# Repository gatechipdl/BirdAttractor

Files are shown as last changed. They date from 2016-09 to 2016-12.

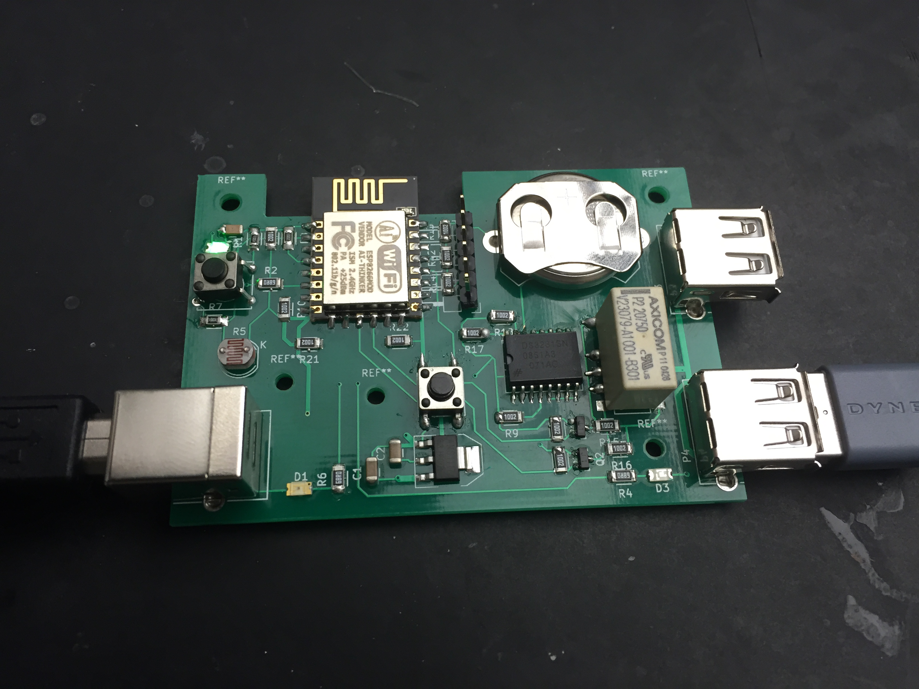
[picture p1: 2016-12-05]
Hardware/BirdAttractor_RevC/BirdAttractor_RevC-Assembled.jpg

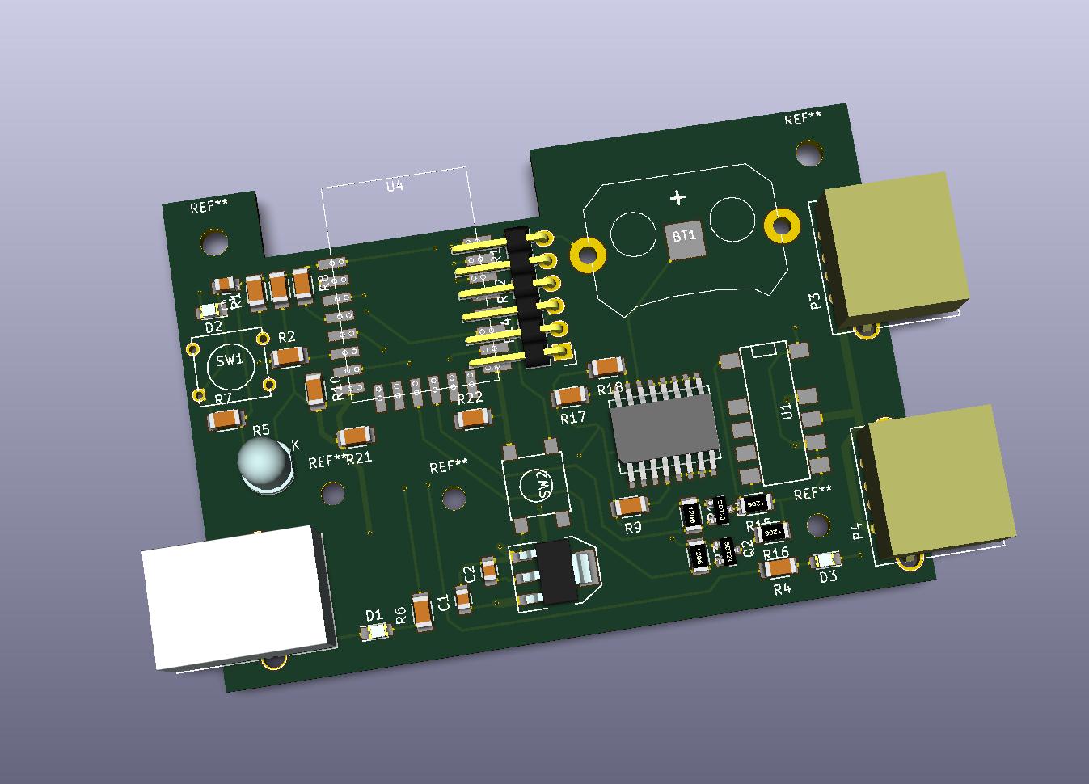
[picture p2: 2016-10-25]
Hardware/BirdAttractor_RevC/BirdAttractor_RevC-Render.jpg

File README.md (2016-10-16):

# BirdAttractor

## Requirements
- 5V Power input from in USB-B female form
- Two 5V Power output in USB-A female form
- Relay to control flow of at least 2A. Possibly more current support for better generalization. Most usb battery chargers are 2A, but some do 3A or 4A.
- Transistors to ensure relay coils trigger from MCU pins. ESP8266 can only drive 12mA on GPIO pins. Relays need >20mA.
 
- Ability to put microcontroller into deep sleep, waking up every 15 seconds to check for updates.
- Infinite alarms for super customization. Not interrupt based, only 15 second accuracy, due to deep sleep wakeup cycle.
- Ability to set the wakeup cycle from 1 second to 5 minutes. ESP8266 GPIO16 pulls CH-DP low during deep sleep. Anything that pulls 
 
- Microcontroller Interrupts for wakeup from deep sleep. ESP8266 can do this from the RTC on GPIO16 connected to reset.
- Two daily alarms for on and off settings. Interrupt based. The alarm interrupt on DS3231 only pulls down to 3mA, so it might need a transistor to boost the current capability to overcome the GPIO16 high signal when in deep_sleep.
 
- FTDI header pins with TX,RX,GND,5V for programming (could be removed if we can program using pogo pins and the firmware is completely debugged).
- Button to control Reset for programming. Button should ideally be hardware debounced, but could probably work without it. ESP8266 needs to pull Reset low, and then GPIO0 low to enter programming mode.
 
- Button to activate Wi-Fi for configuration.
- LED to notify users that the Wi-Fi is on. Should draw less than 12mA.
- LED to show that power is coming in. Should draw less than 12mA.
- LED to show that output power is switched on. Should draw less than 12mA.
 
- Voltage regulator to bring down 5V input to 3.3V for electronics. Should have decoupling capacitors to smooth the supply.
 
- Photoresistor to detect the amount of light for use as a trigger.
-- Ability to configure light based alarm. Five minute response time is sufficient.

- Temperature sensor. Can use the temperature sensor inside the TCXO RTC, which can be good enough.
 
- Real Time Clock with a temperature compensated crystal oscillator (TCXO).
-- Real Time Clock with sub 0C and very high temperature range with high accuracy.
-- Ability to set the timezone on the RTC.
-- Ability to push time from Wi-Fi connected device onto the MCU to update the RTC.

- Record the last X number of light and temperature readings along with when the power was turned on and off, and the timestamp.
-- Option to set the frequency of saving of readings.
-- Option to save X number of samples or to record until there is still memory available.
-- Option to cycle through the available memory or just stop recording when full.
-- Option to reset the samples by clearing the cache.
-- Option to visualize the data in a chart on the web interface.
-- Option to download the data to a Wi-Fi connected web client.
 
---------------
## LED
- Blue LED
- 150080BS75000
- Package:0805
- Forward Voltage: 3.2V
- Max Current: 20mA
- Current Limiting Resistor at 12mA: 16.6 ohms (E12=18 ohms or 22 ohms)
- $0.29@1, digi-key
- $0.23@100, digi-key

---------------
## RTC

### DS1305
- Arduino Library: https://github.com/cjbearman/ds1305-arduino
- Alarms:2
- has two alarms, each alarm must be reset by a read or write to the Alarm interrupt register. Must use an MCU to do this.
- The INT0 and INT1 interrupt output pins are pulled low, so when the alarm asserts, we have to have a pull-up resistor to bring the value up.
- It is likely the INT0 and INT1 pins may not be able to sink enough current to have a small pull up resistor. So with a larger value pull up resistor, the provided current on alarm assertion will be small as well. To magnify this current, a MOSFET may be needed.

### DS1307
- Arduino Library: DS1307RTC, Rtc by Makuna, RTCx 
- TXCO:No, not accurate enough

### DS3231
-Arduino Library: Rtc by Makuna, Sodaq_DS3231
#### DS3231SN
- has temperature compensated crystal oscillator (may need this for cold temps)
- TCXO:Yes
- Alamrs:2
- $9.97@1, digi-key
- $6.59@100, digi-key
- $2.50@10, aliexpress
#### DS3231M
- TCXO: unclear
- $6.46@1, digi-key
- $4.801@50, digi-key

### PCF2129
- TCXO:yes
- Arduino Library: FaBo 215 RTC PCF2129
#### PCF2129T
- Package:16-SOIC
- Temp:-30C to +80C
- $3.36@1, digi-key
- $2.47@100, digi-key
#### PCF2129AT
- Package:20-SOIC, similar as 16-SOIC but with 4 NC pins
- Temp:-15C to +60C
- $2.92@1, digi-key
- $2.15@100, digi-key

### PCF2127
- TXCO:Yes
- Arduino Library: I2C-Sensor-Lib iLib
- includes 512 bytes of general-purpose static RAM
#### PCF2127T
- Package:16-SOIC
- Temp:-30C to +80C
- $4.01@1, digi-key
- $2.95@100, digi-key
#### PCF2127AT
- Package:20-SOIC
- Temp:-15C to +60C
- $3.60@1, digi-key
- $2.65@100, digi-key
 
### PCA2129
- Arduino Library: None Found
- TXCO:Yes
#### PCA2129T
- Package:16-SOIC
- Temp:-30C to +80C
- $4.70@1, digi-key
- $3.46@100, digi-key

### MCP79400
- TXCO:No
- Arduino Library: RTCx (includes MCP7941x)
- accuracy potentially better than ds1307 and pcf8563, but not ds3231
- $0.82@1, digi-key
- $0.72@100, digi-key

---------------
## Relay
- latching, dual coil, bistable
- contact current: 2,3-10 Amps (2A seems an industry threshold)
- coil voltage: 3.3V,5V
- coil current: <100mA
- switching voltage: >5VDC

### V23079
- Current:2A
#### V23079-E1201-B301
- Signal Volage:3.75V-5V
- Signal Current:28mA
- Latching:Yes
- Bistable:Yes
- $3.69@1, digi-key
- $2.77@100, digi-key
#### V23079-A1001-B301
- $5.17@10, aliexpress
- Monstable:Yes
- Bistable:No
- standard coil, coil 001
- standard version, 2 form C contacts

### TX2SA
#### TX2SA-LT-5V-TH-Z
- Signal Volage:5V
- Signal Current:28.1mA
- Current:2A
- $5.83@1, digi-key
- $4.38@100, digi-key

### G6BK (5A, twice as expensive as 2A)
#### G6BK-1114P-US-DC5
- Signal Voltage:5V
- Signal Current:56mA
- Current:5A
- $7.61@1, digi-key
- $5.71@100, digi-key

### AQV25
- Type:solid state
### AQV251G
- Package:6-DIP
- Current:3.5A
- Voltage:0-30V
- $7.75@1, digi-key
- $5.85@100, digi-key
### AQV252G
- Package:6-SOIC
- Current:2.5A
- Voltage:0-60V
#### AQV252GAX
- Tape and Reel packaging on 123 pin side
- $5.39@1, digi-key
- $4.04@100, digi-key
#### AQV252GAZ
- Tape and Reel packaging on 456 pin side
#### AQV252GA
- Tube packing style

---------------
## Coin Cell Retainer/Holder
- Battery:CR2032
- Battery Diameter:20mm
### BU2032
#### BU2032-1-HD-G
- Type:through hole holder
- $0.83@1, digi-key
- $0.69@100, digi-key
#### BU2032SM-HD-G
- Type:surface mount holder
- $0.87@1, digi-key
- $0.76@100, digi-key
### BK
#### BK-913
- Type:through hole retainer
- Notes:easy replacement
- $0.35@1, digi-key
- $0.30@100, digi-key
#### BK-888
- Type:through hole retainer
- blocks inner side
- easy replacement
- $0.39@1, digi-key
- $0.33@100, digi-key

---------------
## LDO
- needed for running the esp8266 microprocessor
### AMS1117-3.3
- Package:SOT-223
- $1.58@50, aliexpress

---------------
## MCU
### ESP8266
- Wi-Fi:Yes
- Allows us to have a Wi-Fi interface for setting the time and other settings.
- VCC:3.3V
- Runs on 3.3V, so should have an LDO or similar to bring down the 5V supply.
- Should only be turned in two instances. First is to creating the Wi-Fi interface. Second is at an alarm, to turn off the alarm, and then shut itself down. If we use deep sleep, then we could check every 5 minutes (or less) to see if the alarm pin is pulled high.
- It might be possible to use the reset pin on the ESP8266 to wake it up with the alarm. This would be more power efficient and have better reaction time (within milliseconds) to the alarm assertion, but the solution is more complex and takes longer to develop. https://github.com/esp8266/Arduino/issues/1488
- pin mapping: http://www.esp8266.com/wiki/doku.php?id=esp8266_gpio_pin_allocations

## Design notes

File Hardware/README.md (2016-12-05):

RevA - first version
RevB - with correct parts, and partial design for in house milling; through hole parts flipped to bottom
RevC - layout with parts on top for fab house milling
 - problems
 -- smd button melts with 800 degree heat
 -- through-hole 6mm button legs don't fit well into holes
 -- missing a few 1206 sized resistors
 -- battery backwards due to kicad default battery pinout
 -- battery rotated backwards too on board; curved portion is where button slides in
 -- some LEDs on by default; check that is correct; should be able to disable
 -- relays are only monostable, not latching; only has one input; ok bc can be compensated for in code
 -- relays are throughole; should design for smd and tht too

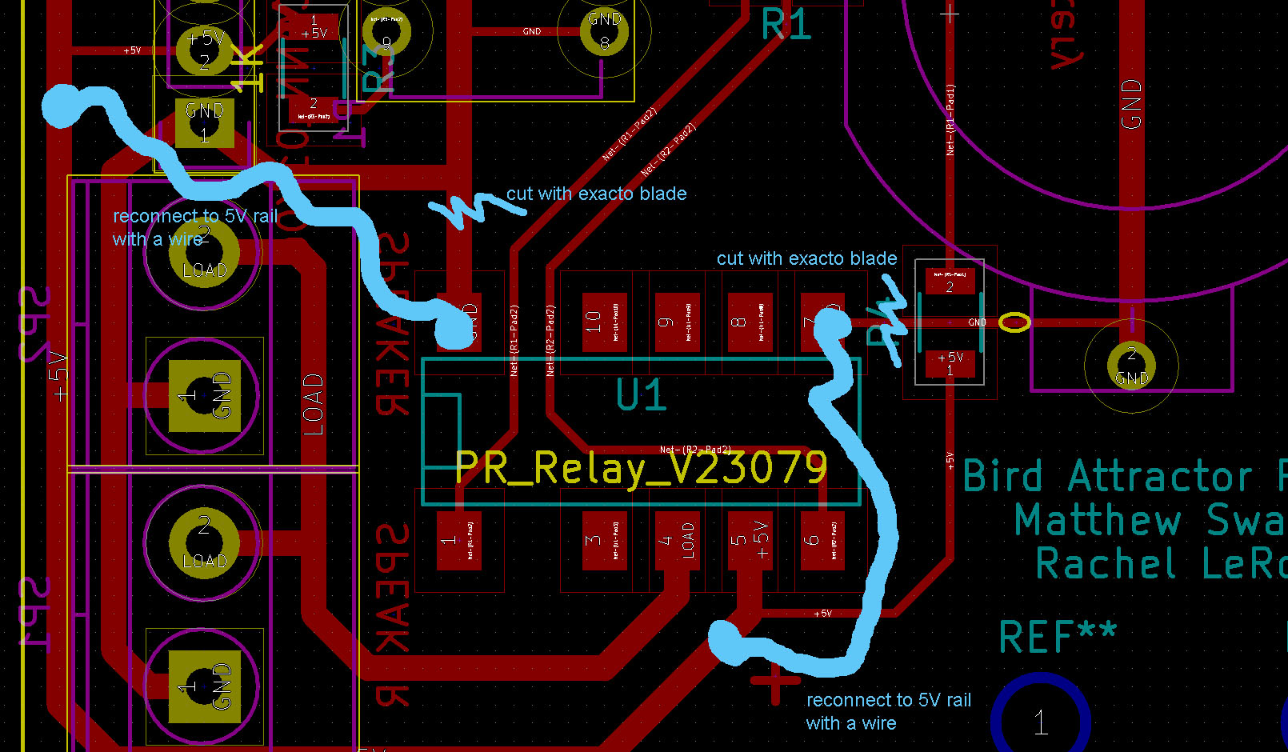
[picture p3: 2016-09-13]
Hardware/BirdAttractor_RevAFix.jpg

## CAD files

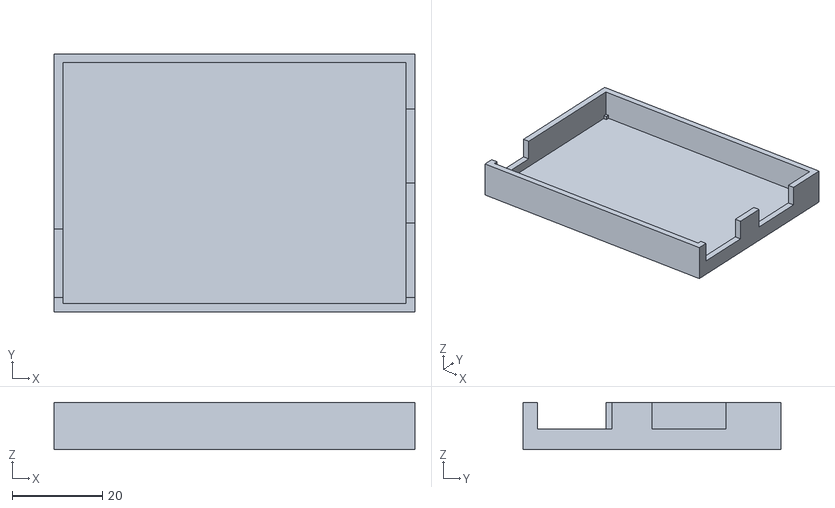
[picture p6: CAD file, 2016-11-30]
Models/3D.form.v1/bottom stl.stl
80.2 x 57.3 x 10.6

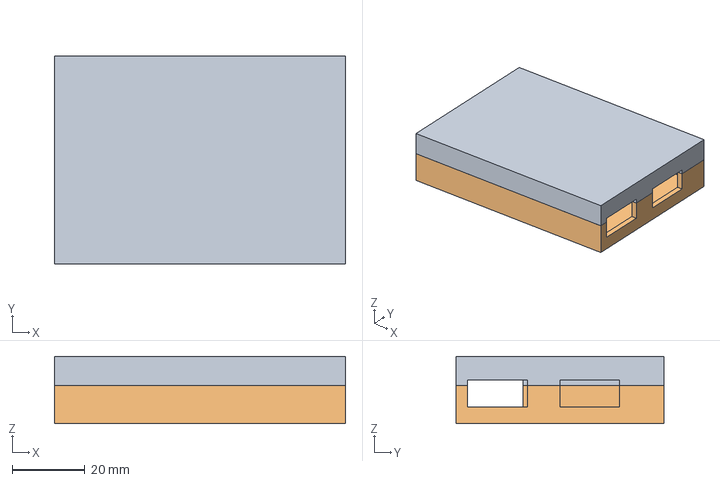
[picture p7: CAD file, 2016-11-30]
Models/3D.form.v1/box for hardware v9.step
80.2 x 57.3 x 18.5 mm
top
bottom

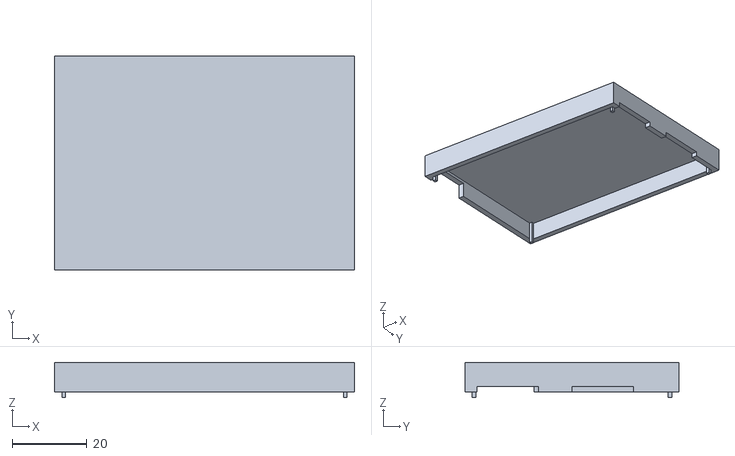
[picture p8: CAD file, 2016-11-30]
Models/3D.form.v1/top.stl
80.2 x 57.3 x 9.45

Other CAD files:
Models/3D.form.v1/box for hardware v9.f3d
Models/3D.form.v1/box for hardware v9.iges

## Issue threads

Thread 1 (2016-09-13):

design basic form for board components and case

strontium5, 2016-09-13:
arduino shield form
pin locations
power plug-ins
battery changing (every 8 years)

racheleleroy, 2016-10-31:
this isn't for the the 3D form, but for the UI. Couldn't figure out how to upload new file, kept saying I didn't have that authorization.

Very basic UI, still working on learning html, css, js but wanted to get some basic skeleton for mvp after doing the tutorials to exercise the new things in my head.
[bird attractor device rach's comp.zip](https://github.com/gatechipdl/BirdAttractor/files/561059/bird.attractor.device.rach.s.comp.zip)

strontium5, 2016-10-31:
this is for the 3D form

On Sun, Oct 30, 2016 at 11:35 PM, racheleleroy <notifications@github.com>
wrote:

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

strontium5, 2016-10-31:
You should be able to commit now.
Also, I added issues related to the UI. You can change them as you see fit.

racheleleroy, 2016-11-12:
3D files for the form to hold the board and components. Built in fusion360. The two stl files are each half of the box (top and bottom) separate so that they can easily be processed in the design shop. The other files are a variety of 3d files for good measure.

[3D form v1.zip](https://github.com/gatechipdl/BirdAttractor/files/587514/3D.form.v1.zip)

strontium5, 2016-11-30:
should be moved into the github code section under models ( I will create and do that now)

strontium5, 2016-11-30:
uploaded.
you can use the RevC pcb layout pdf file to get mounting hole and component positions for the next version of the case:
https://github.com/gatechipdl/BirdAttractor/blob/master/Hardware/BirdAttractor_RevC/BirdAttractor_RevC-Layout.pdf

strontium5, 2016-12-05:
@racheleleroy I added a photo of the assembled Rev C board. There are a few issues, but it should work. I haven't started on the basic firmware yet, but I did add the issues to the github issues list. I'll leave this board in our project box in the IPDL.

racheleleroy, 2016-12-06:
@strontium thanks for moving it to models and for the photo. Ill stop by and take a look at the board. I can have v2 by end of weekend. I'll slip it onto the design shop machines while I work this weekend

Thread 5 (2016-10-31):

design overall UI/UX for all pages hosted on device

strontium5, 2016-10-31:

racheleleroy, 2016-11-28:
[bird.att.take.two.zip](https://github.com/gatechipdl/BirdAttractor/files/615287/bird.att.take.two.zip)
Work on the bootstrap UI. No specific UI for picking date and time yet. There are some plugins we can use - going by the app lab tomorrow (monday) to get help understanding how to set them up across the html, css, and js

strontium5, 2016-11-30:
need to remove/replace references to external sites, such as for javascript libraries. This will not be connected to the internet.
This line is a problem:
<script src="//ajax.googleapis.com/ajax/libs/jquery/1.11.2/jquery.min.js"></script>
There is a local version of jquery in the js folder, which should be referenced instead.

It is looking alright so far. May need to distinguish between first time users, and those who just want to go and set the time.

While this device is being developed for the bird attractor, it is really much more generic than that. It is a device for setting 5v relay alarms over wifi. Should we make a distinction in the text (ie scientist vs user)?

strontium5, 2016-11-30:
Also, you can just put your code into the github. You won't need to create different version names for this code either, as github will maintain every version. I can put it in if you want. But eventually you should learn how to use git.

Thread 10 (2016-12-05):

swap out SW1 from 6mm to 12mm tht button

strontium5, 2016-12-05:

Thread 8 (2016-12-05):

fix coin cell battery orientations

strontium5, 2016-12-05:
rotated 180 degrees and the positive and ground are reversed

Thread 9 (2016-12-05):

redesign relay pinouts to support smd and tht and for mono and bi stable versions

strontium5, 2016-12-05:

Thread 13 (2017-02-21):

optionally replace relay with a power mosfet

strontium5, 2017-02-21:
power mosfet is cheaper and more powerful than relay for small voltages (eg 5V).
pnp power mosfet should probably use npn bjt before to increase the Vgs
npn bjt could be 2n3904 or 2n2222
pnp power mosfet could be FQP27P06 or Si3483

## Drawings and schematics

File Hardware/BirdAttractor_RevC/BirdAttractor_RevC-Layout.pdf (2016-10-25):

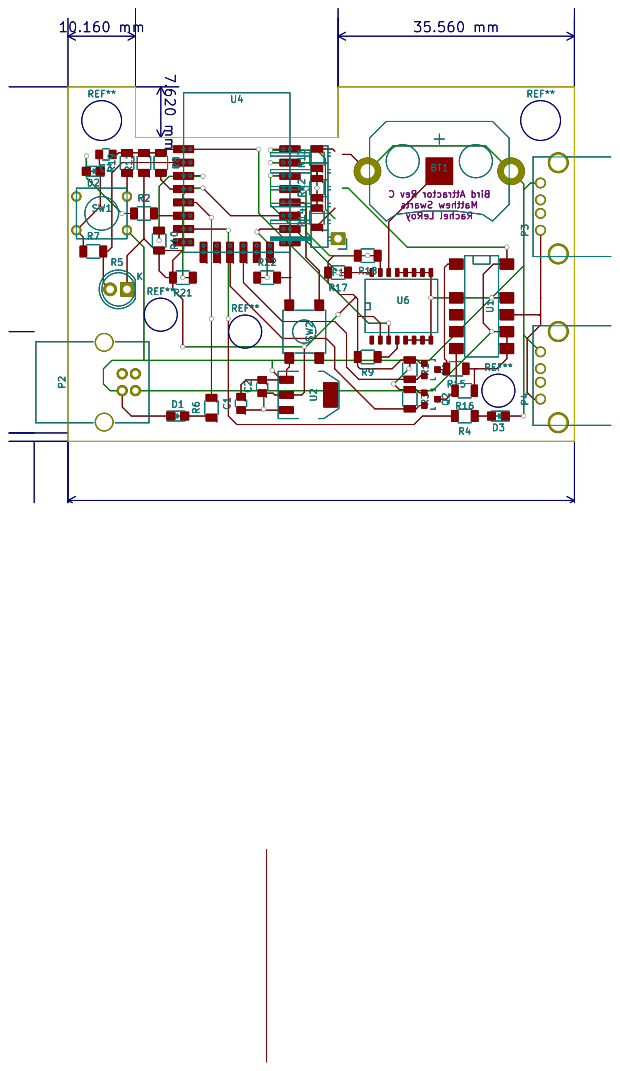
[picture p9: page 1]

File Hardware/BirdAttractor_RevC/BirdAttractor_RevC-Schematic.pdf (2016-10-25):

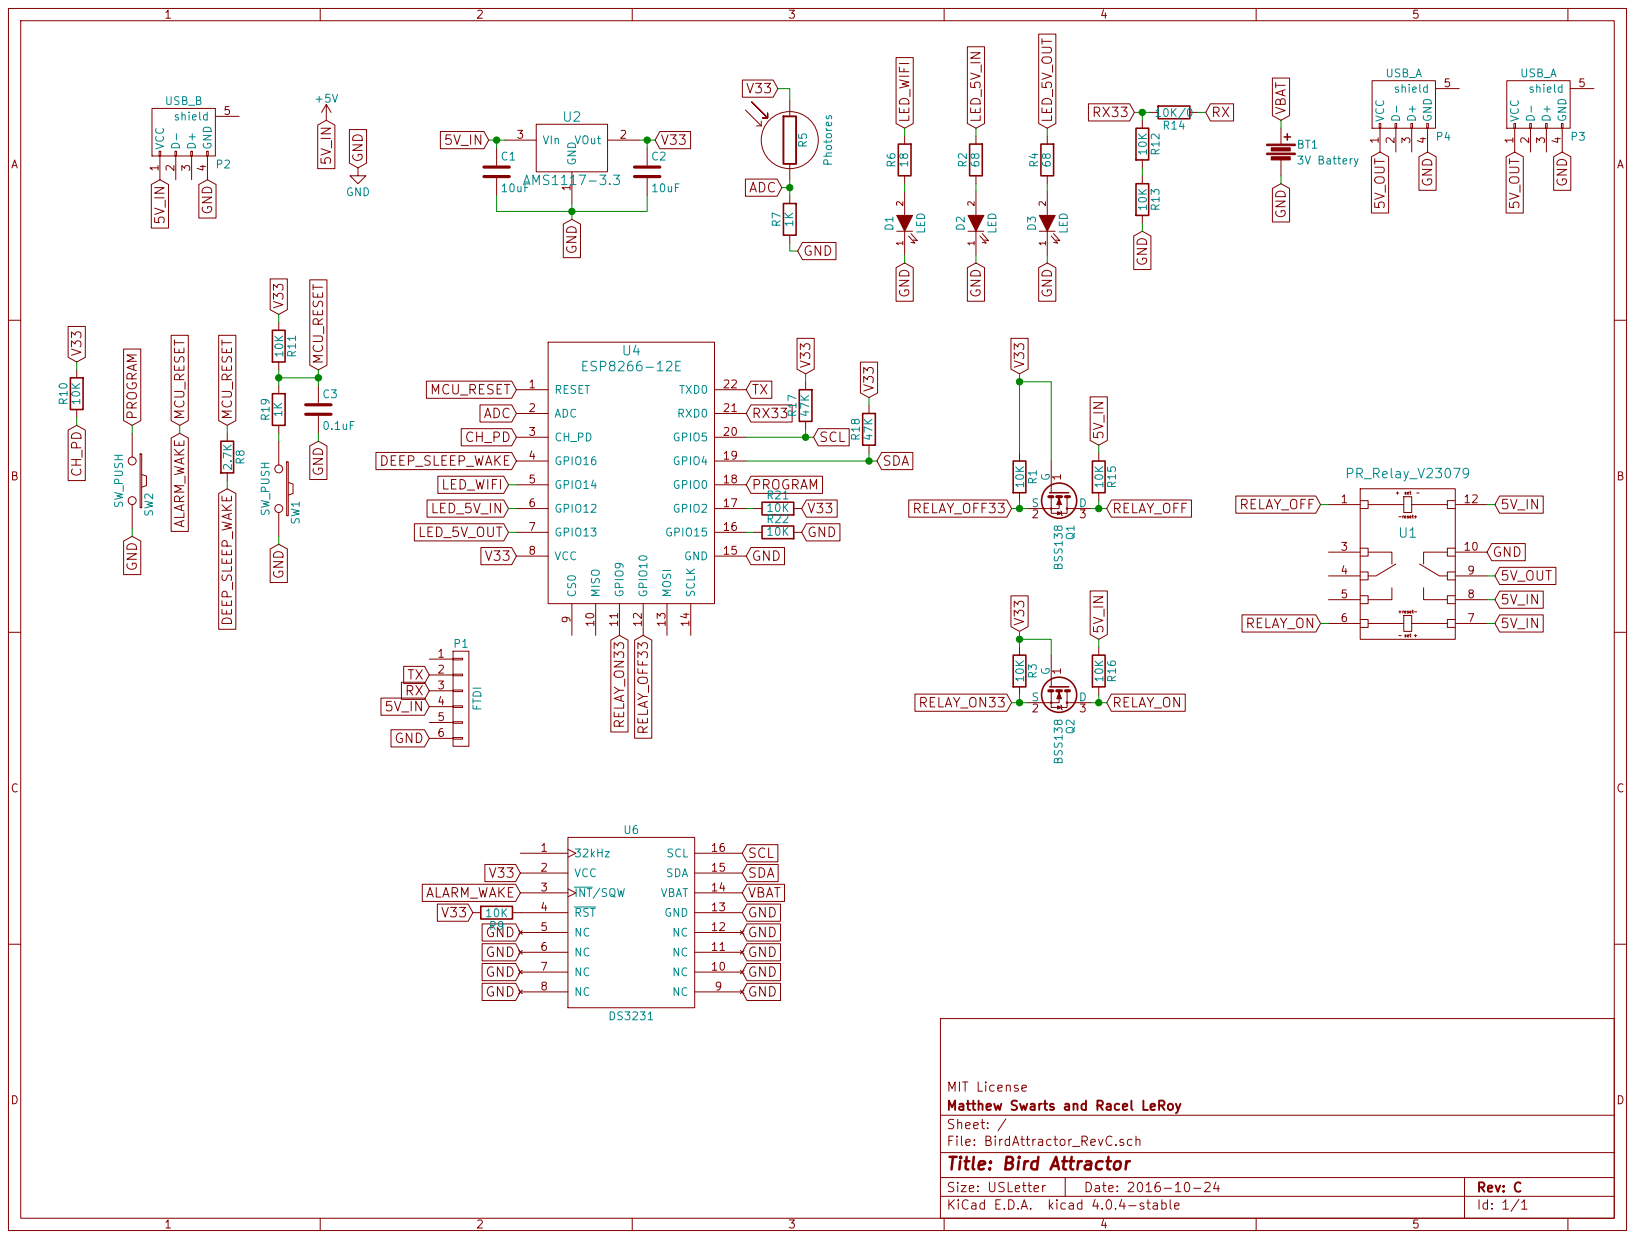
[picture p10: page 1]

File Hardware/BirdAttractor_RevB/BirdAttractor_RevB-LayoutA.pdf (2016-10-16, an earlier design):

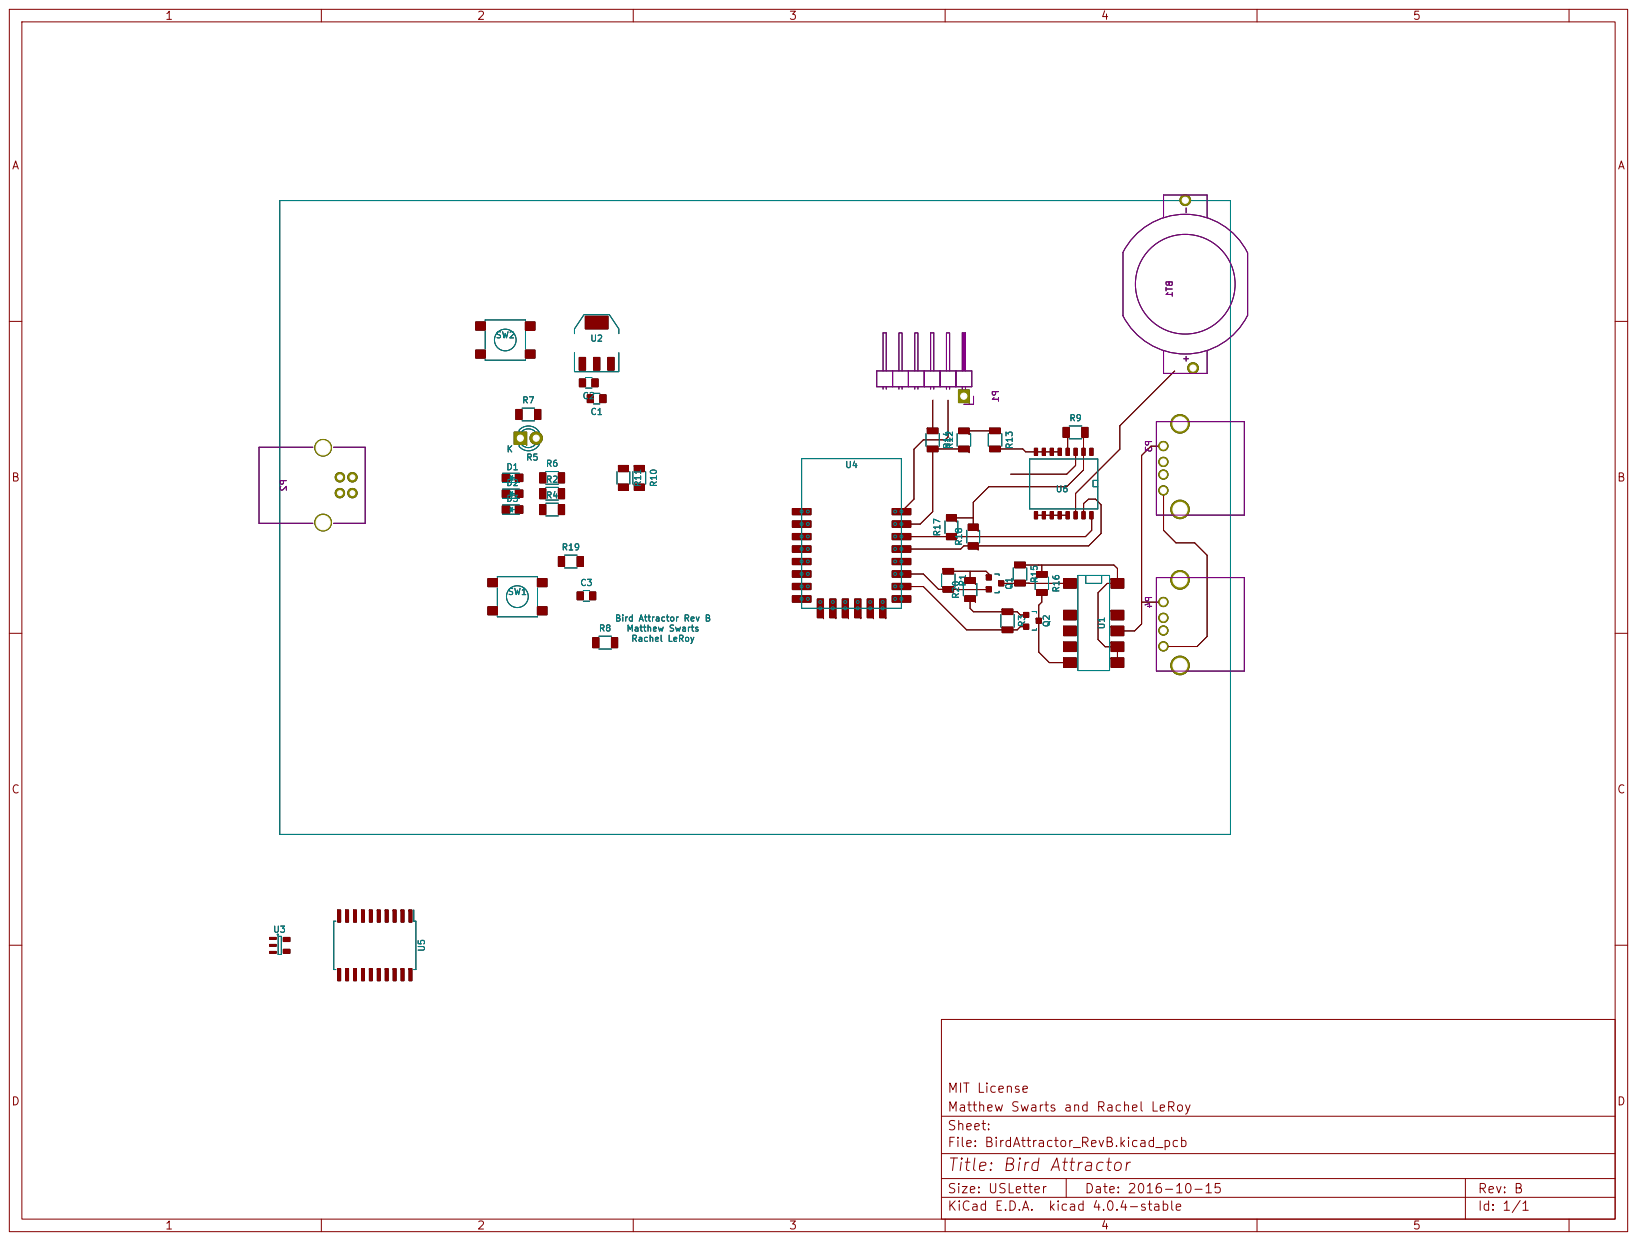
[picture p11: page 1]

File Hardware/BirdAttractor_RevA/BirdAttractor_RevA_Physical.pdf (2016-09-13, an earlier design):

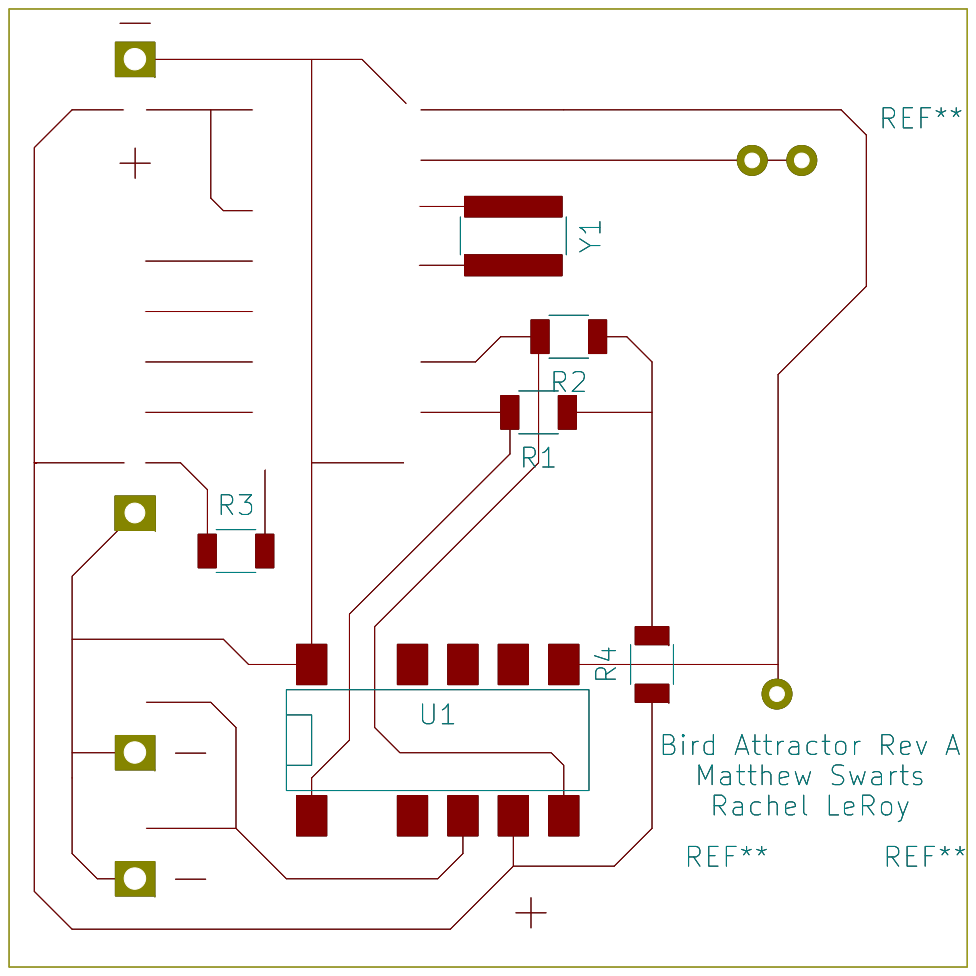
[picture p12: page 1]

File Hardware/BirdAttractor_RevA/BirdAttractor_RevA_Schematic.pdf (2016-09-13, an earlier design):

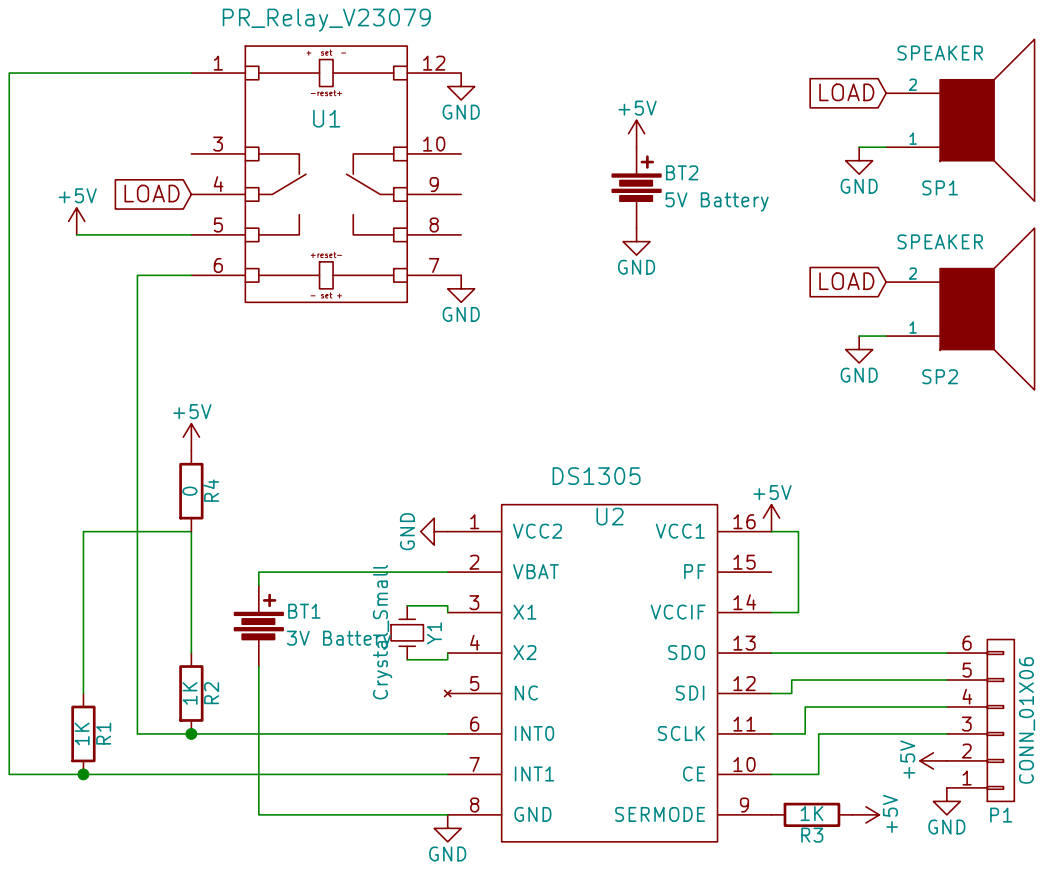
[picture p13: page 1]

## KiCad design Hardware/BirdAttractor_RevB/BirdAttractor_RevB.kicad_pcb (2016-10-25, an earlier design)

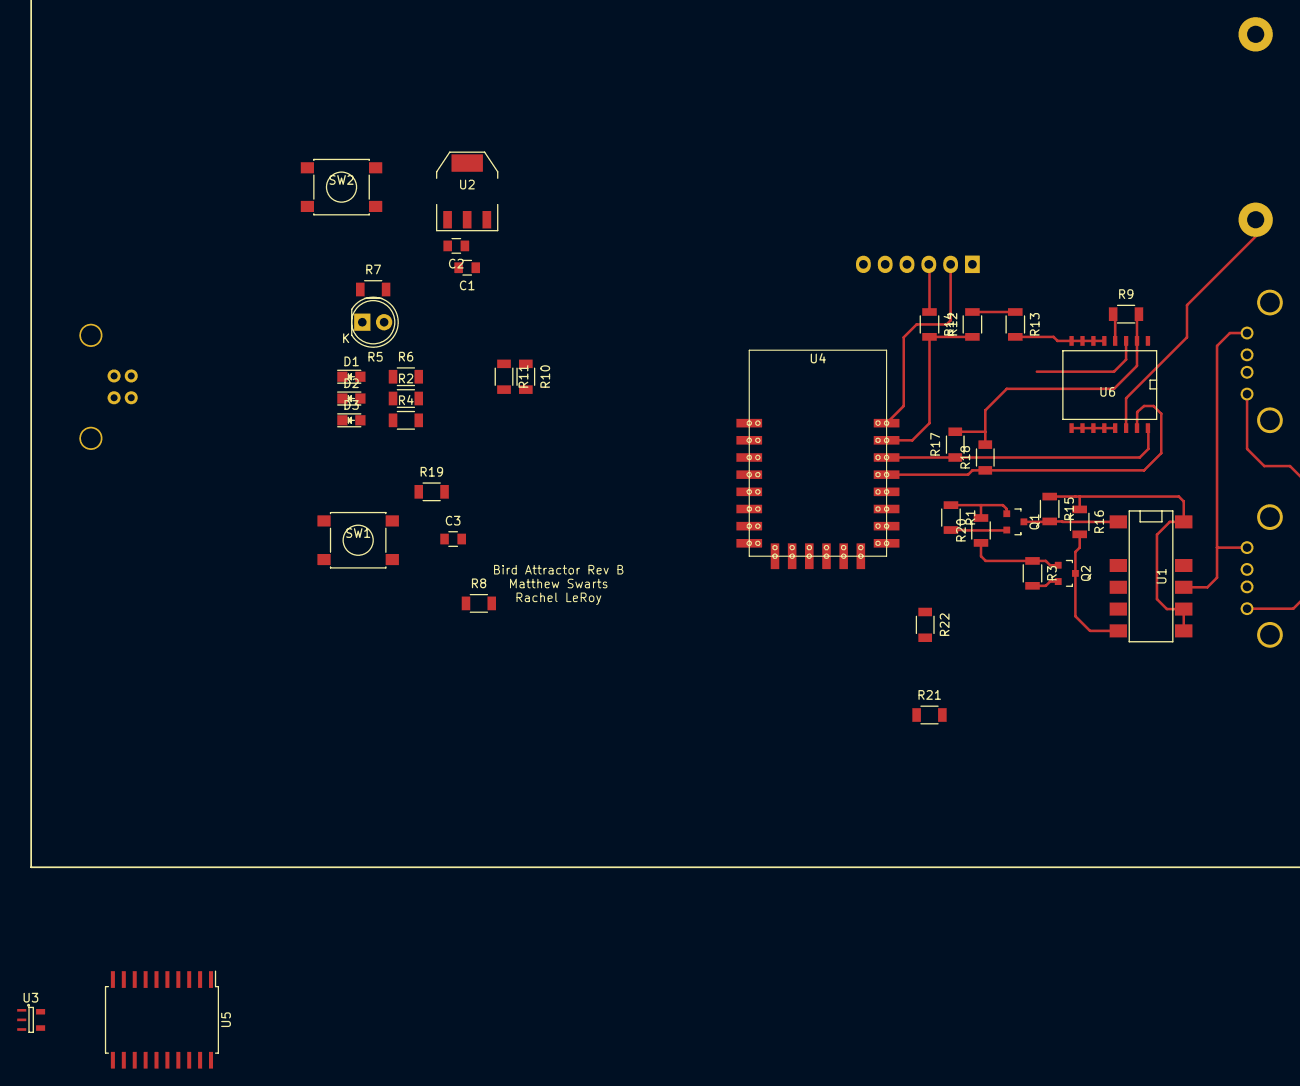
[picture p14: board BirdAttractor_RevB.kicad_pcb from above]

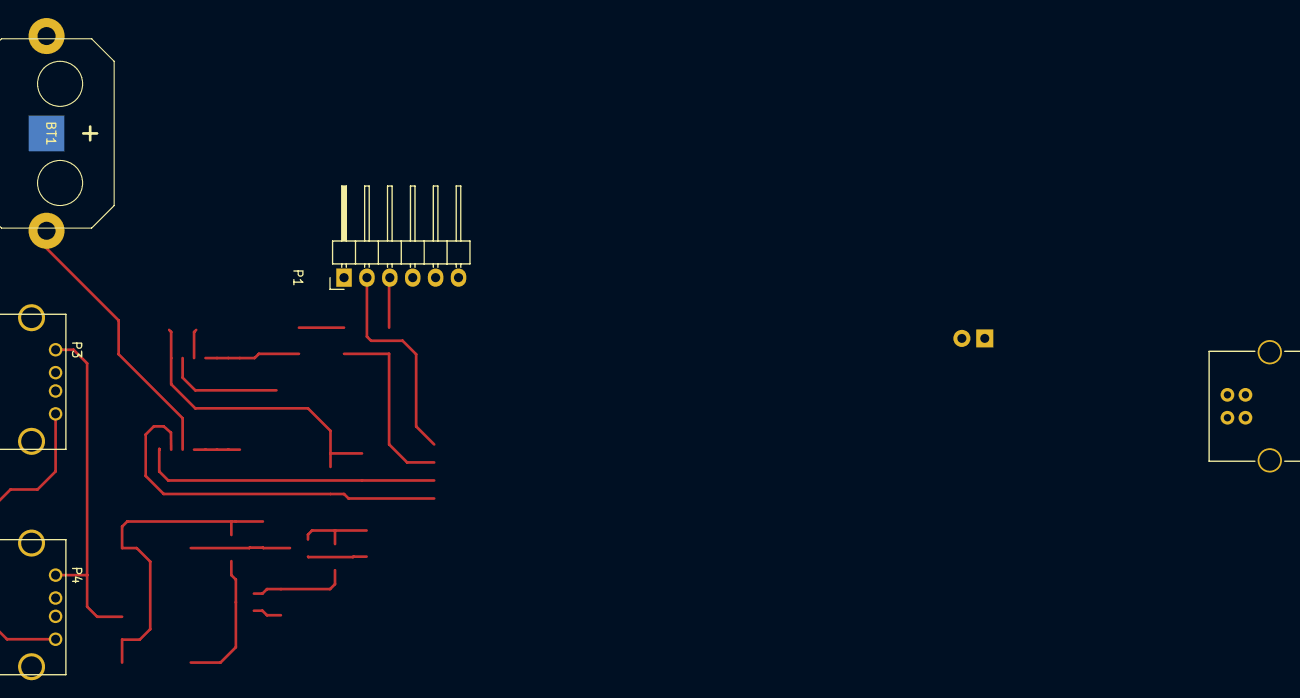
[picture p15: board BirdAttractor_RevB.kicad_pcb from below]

Board: 2 copper layers, 43 parts (5 on the bottom side), 30 nets.

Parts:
BT1: 3V Battery; BK-913
C1: 1uF; C_0805
C2: 10uF; C_0805
C3: 0.1uF; C_0805
D1, D2, D3: LED; LED-0805
P1: FTDI; Pin_Header_Angled_1x06
P2: USB_B
P3, P4: USB_A
Q1, Q2: BSS138; SOT-23
R1, R3, R12, R13, R15, R16: 10K; R_1206
R2, R4: 68; C_1206
R5: Photores; LED-5MM
R6: 18; C_1206
R7, R19: 1K; C_1206
R8: 2.7K; C_1206
R9: 100K; C_1206
R10, R11, R21, R22: 10K; C_1206
R14: 10K/0; R_1206
R17, R18: 47K; C_1206
R20: 0; R_1206
SW1, SW2: SW_PUSH; SW_SPST_PTS645
U1: PR_Relay_V23079; DIP-12-SMD
U2: AMS1117-3.3; SOT-223
U3: SN74LVC1G14; SOT-23-5-80
U4: ESP8266-12E; ESP8266-12E-80
U5: PCF2129AT; SOIC-20_7.5x12.8mm_Pitch1.27mm-80
U6: DS3231; SO-16-W

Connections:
5V_IN: C1.1, P1.4, P2.1, R15.1, R16.1, U1.7, U1.8, U1.12, U2.3
5V_OUT: P3.1, P4.1, U1.9
ADC: R5.2, R7.2, U4.2
ALARM_WAKE: C3.1, R8.1, R11.2, R19.2, U4.1, U6.3
CH_PD: R10.1, U4.3
DEEP_SLEEP_WAKE: R8.2, U4.4
GND: BT1.2, C1.2, C2.2, C3.2, D1.1, D2.1, D3.1, P1.6, P2.4, P3.4, P4.4, R7.1, R13.2, R22.2, SW1.2, SW2.2, U2.1, U4.15, U6.5, U6.6, U6.7, U6.8, U6.9, U6.10, U6.11, U6.12, U6.13
LED_5V_IN: R2.2, U4.6
LED_5V_OUT: R4.2, U4.7
LED_WIFI: R6.2, U4.5
unnamed: D1.2, R6.1
unnamed: D2.2, R2.1
unnamed: D3.2, R4.1
unnamed: R9.1, U6.4
unnamed: R12.2, R13.1
unnamed: R19.1, SW1.1
unnamed: R21.1, U4.17
unnamed: R22.1, U4.16
PROGRAM: SW2.1, U4.18
RELAY_OFF: Q1.3, R15.2, U1.1
RELAY_OFF33: Q1.2, R1.2, U4.12
RELAY_ON: Q2.3, R16.2, U1.6
RELAY_ON33: Q2.2, R3.2, U4.11
RX: P1.3, R14.1
RX33: R12.1, R14.2, U4.21
SCL: R17.1, U4.20, U6.16
SDA: R18.1, U4.19, U6.15
TX: P1.2, U4.22
V33: C2.1, Q1.1, Q2.1, R1.1, R3.1, R5.1, R9.2, R10.2, R11.1, R17.2, R18.2, R20.1, R20.2, R21.2, U2.2, U4.8, U6.2
VBAT: BT1.1, U6.14

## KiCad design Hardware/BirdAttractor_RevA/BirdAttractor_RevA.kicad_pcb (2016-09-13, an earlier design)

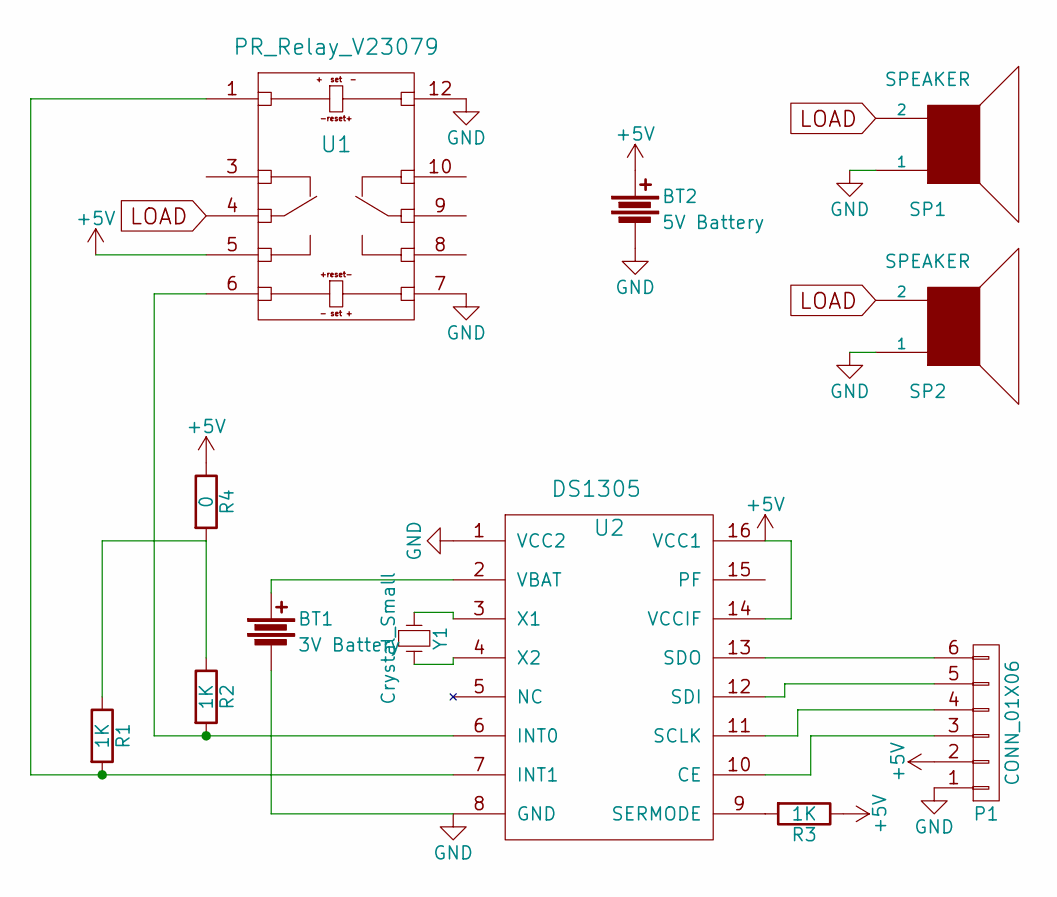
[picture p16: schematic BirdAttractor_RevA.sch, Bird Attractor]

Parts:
BT1: 3V Battery; BU2032-1-HD-G
BT2: 5V Battery; TerminalBlock_Pheonix_MPT-2.54mm_2pol
P1: CONN_01X06; Socket_Strip_Straight_1x06
R1, R2, R3: 1K; R_1206
R4: 0; R_1206
SP1, SP2: SPEAKER; TerminalBlock_Pheonix_MPT-2.54mm_2pol
U1: PR_Relay_V23079; DIP-12-SMD
U2: DS1305; DIP-16_W7.62mm
Y1: Crystal_Small; R_1218

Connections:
+5V: BT2.1, P1.2, R3.1, R4.1, U1.5, U2.14 (VCCIF), U2.16 (VCC1)
GND: BT1.2, BT2.2, P1.1, SP1.1, SP2.1, U1.7, U1.12, U2.1 (VCC2), U2.8 (GND)
LOAD: SP1.2, SP2.2, U1.4
unnamed: BT1.1, U2.2 (VBAT)
unnamed: P1.3, U2.10 (CE)
unnamed: P1.4, U2.11 (SCLK)
unnamed: P1.5, U2.12 (SDI)
unnamed: P1.6, U2.13 (SDO)
unnamed: R1.1, R2.1, R4.2
unnamed: R1.2, U1.1, U2.7 (INT1)
unnamed: R2.2, U1.6, U2.6 (INT0)
unnamed: R3.2, U2.9 (SERMODE)
unnamed: U2.3 (X1), Y1.1
unnamed: U2.4 (X2), Y1.2

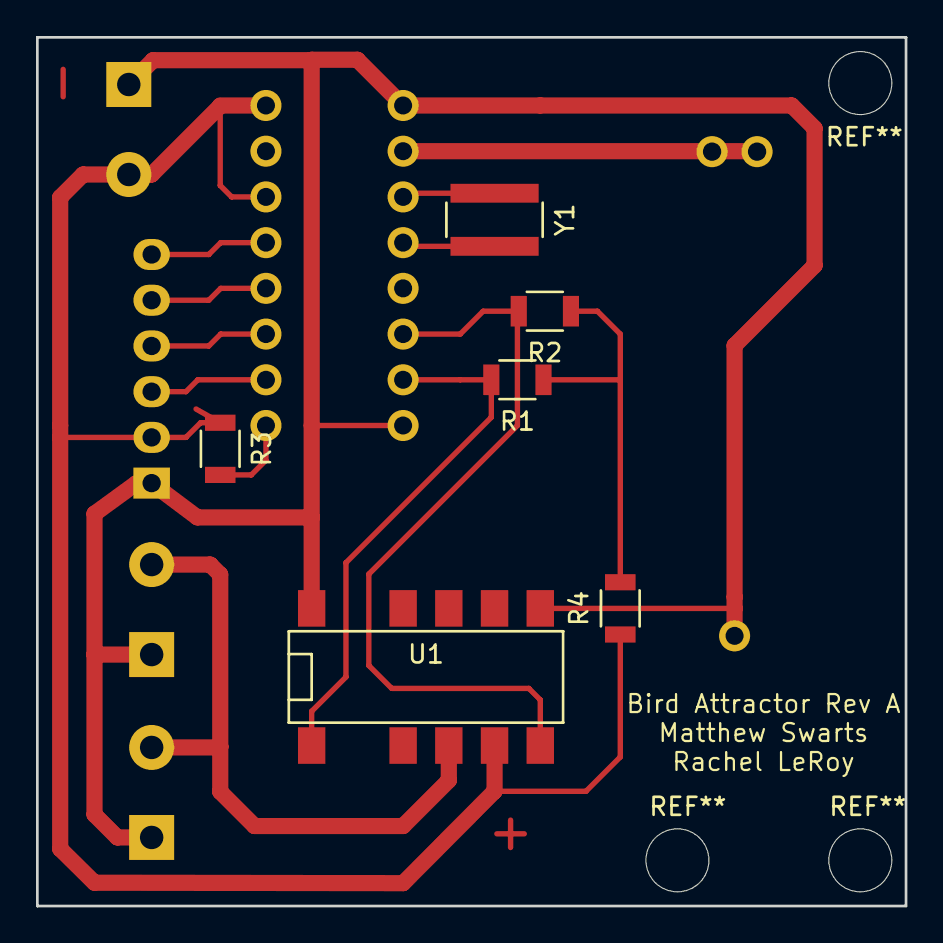
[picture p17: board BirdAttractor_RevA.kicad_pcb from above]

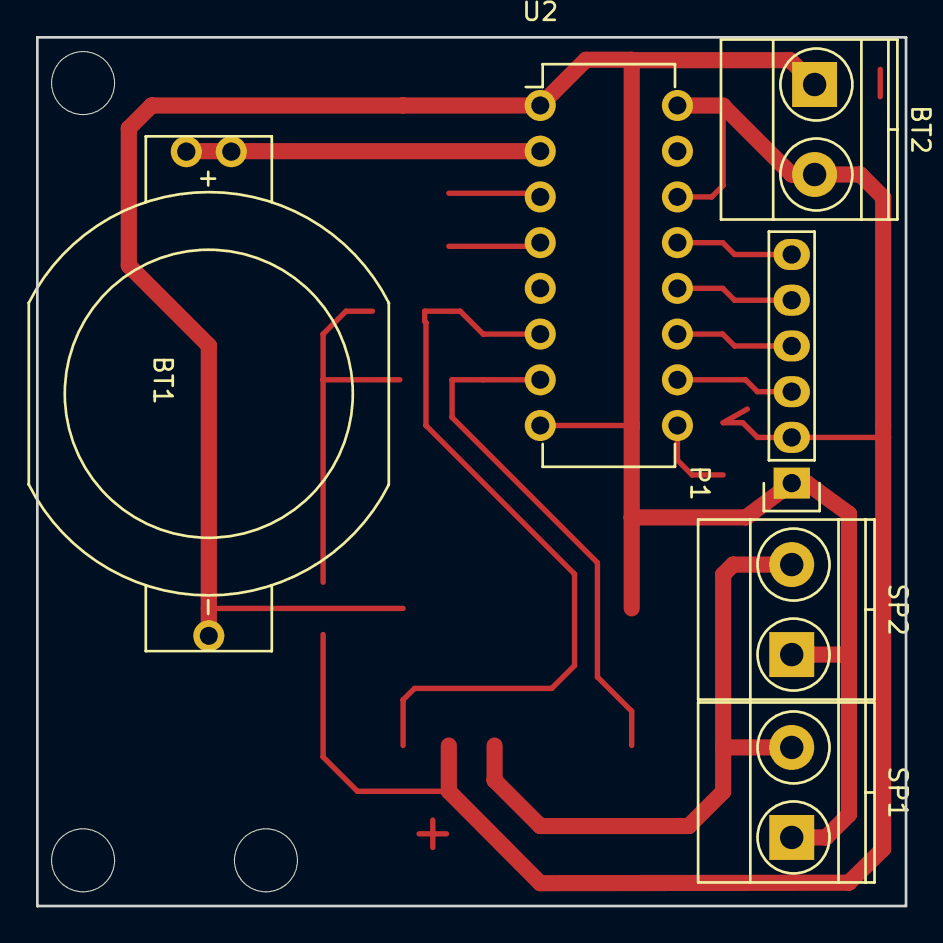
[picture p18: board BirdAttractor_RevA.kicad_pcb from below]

Board: 2 copper layers, 48.3 x 48.3 mm, 12 parts (6 on the bottom side), 14 nets.

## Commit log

2016-09-13 added hardware files
    [BirdAttractor_RevA.kicad_pcb, BirdAttractor_RevA.sch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]
2016-10-12 added notes on parts in readme, added new revision to the board with newly selected parts
    [BirdAttractor_RevB.kicad_pcb, BirdAttractor_RevB.sch]
2016-10-14 added more components and more notes in the readme
    [BirdAttractor_RevB.sch]
2016-10-15 added low pass debounce filter, added connections for different wake up functions, began layout design for in house pcb.
    [BirdAttractor_RevB.kicad_pcb, BirdAttractor_RevB.sch]
2016-10-16 minor updates
    [BirdAttractor_RevB.kicad_pcb]
2016-10-25 added pull down resistor to gpio15 for programming; created RevC and board ready for fabrication
    [BirdAttractor_RevB.kicad_pcb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]
2016-11-30 added models and software
    [bottom stl.stl, box for hardware v9.f3d, box for hardware v9.iges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]
2016-12-05 added photo of Rev C board assembled listed problems with Rev C board to be addressed in the next version.

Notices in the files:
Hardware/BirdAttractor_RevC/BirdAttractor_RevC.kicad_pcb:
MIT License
